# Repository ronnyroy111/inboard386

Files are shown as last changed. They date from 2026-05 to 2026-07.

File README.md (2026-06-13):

# Intel Inboard 386/PC Clone
https://forum.theretroweb.com/t/intel-inboard-386-pc-accelerator-clone/44

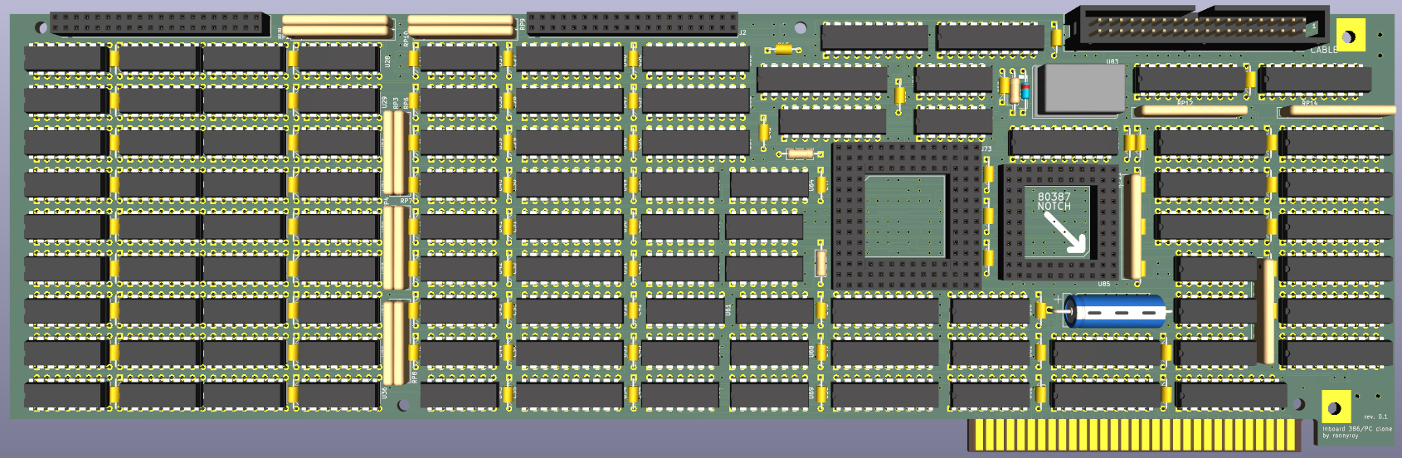
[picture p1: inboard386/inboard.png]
  
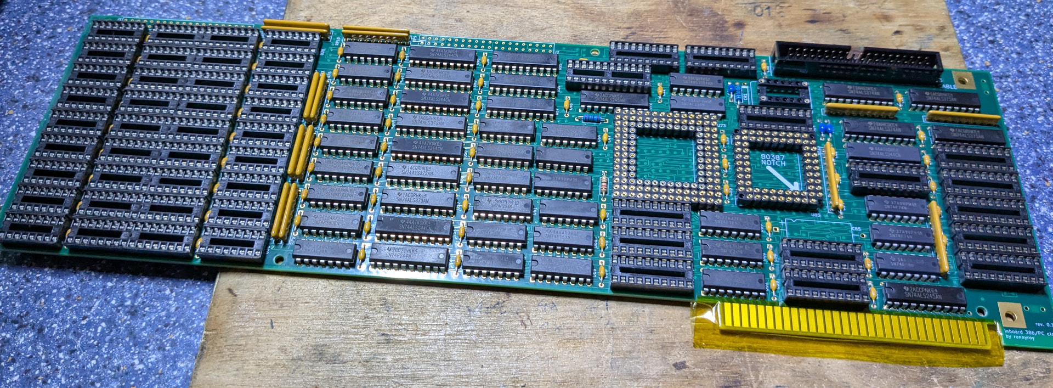
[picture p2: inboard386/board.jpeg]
  
This is a project to reverse engineer and reproduce the [Intel Inboard 386/PC Accelerator Card](https://theretroweb.com/expansioncards/s/intel-inboard-386-pc).  
It's based on a damaged card that i obtained a while ago and managed to fix but decided to sacrifice for a reproduction.  
The Inboard 386/PC is an upgrade card from Intel for the IBM PC/XT and clones that upgraded the 8088 CPU to a 16MHz 386DX and up to 5MB of system memory.  
The card only uses standard 74 series logic chips along with some PALs/PROMs that were luckily not secured and were successfully dumped.  
The PCB is a 6 layer design with 4 signal layers. To aid with reverse engineering it i ended up choosing the destructive route and sanded the entire PCB down to the inner layers.  
By now the PCB design has been completed while the schematic still needs cleanup and further reverse engineering of the programmable logic to completely understand.  

The first revision of the board has been tested and confirmed to be working.  
GAL replacements for the PAL chips and a PROM replacement board have been tested as well.  
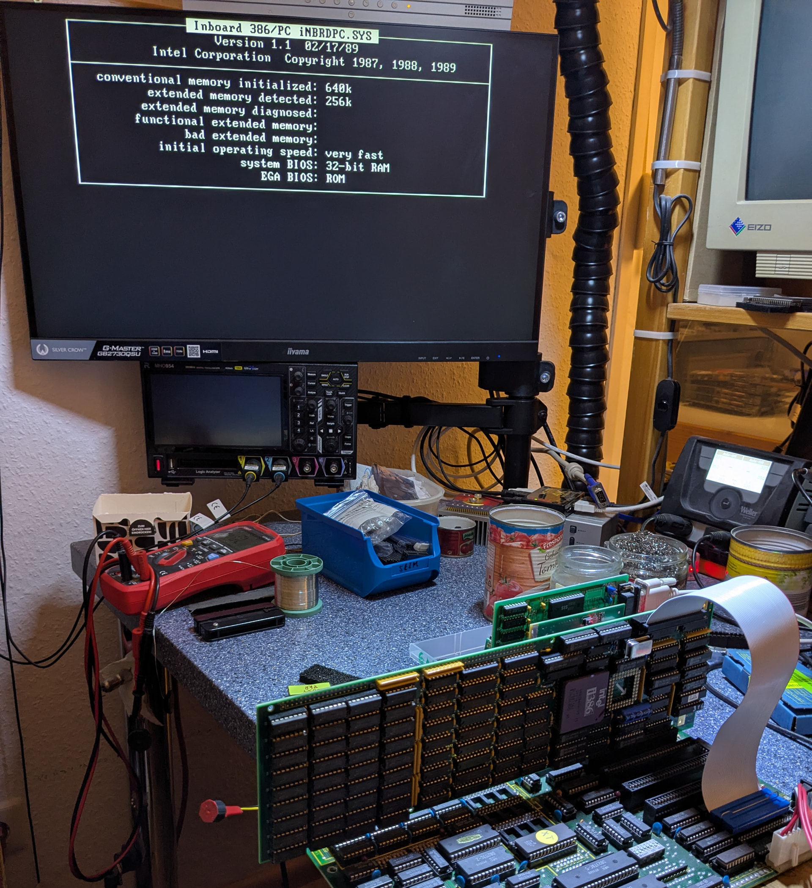
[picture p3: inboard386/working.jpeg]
  
A memory expansion board is currently in work.

This current board design is a 1:1 copy of the original PCB, excluding some small details.  
A future plan is to do a redesign to condense parts of the logic into one or more CPLDs and integrate the optional external memory expansion boards into the design

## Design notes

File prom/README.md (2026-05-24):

A small adapter PCB to replace the 63S281 PROM at U98 with a modern PLCC EEPROM.

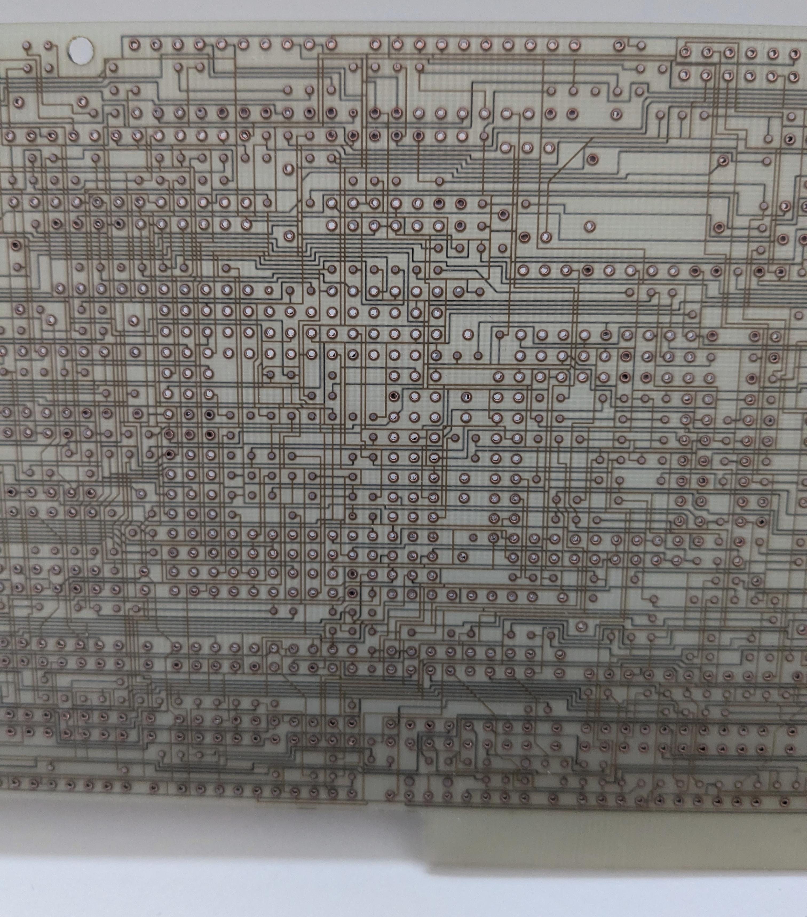
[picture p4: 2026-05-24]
inboard386/inner.jpg

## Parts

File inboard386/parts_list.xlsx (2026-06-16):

Part: | Quantity: | Mouser PN: | MFG PN: | alt Mouser PN: | Notes:
100nF capacitor | 69 | 80-C410C104Z5U | C410C104Z5U5TA | 80-C410C104Z5U-TR
180pF capacitor | 2 | 594-A181K15X7RF5TAA | A181K15X7RF5TAA
22pF capacitor | 1 | 594-A220J15C0GF5UAA | A220J15C0GF5UAA
560µF capacitor | 1 | 594-MAL212636561E3 | MAL212636561E3
115 ohm resistor | 1 | 603-MFR-25FBF52-115R | MFR-25FBF52-115R | 603-MFR-25FRF52-115R
12 ohm resistor | 1 | 603-CFR-25JB-52-12R | CFR-25JB-52-12R
1k ohm resistor | 1 | 603-CFR25SJT-52-1K | CFR25SJT-52-1K
74F74 | 7 | 595-SN74F74N | SN74F74N
74ALS373 | 6 | 595-SN74ALS373AN | SN74ALS373AN
74ALS244 | 5 | 595-SN74ALS244CN | SN74ALS244CN
74ALS245 | 5 | 595-SN74ALS245AN | SN74ALS245AN
74F280 | 4 | 595-SN74F280BN | SN74F280BN
74F258 | 4 | 595-SN74F258N | SN74F258N
74AS1004 | 3 | 595-SN74AS1004AN | SN74AS1004AN |  | could maybe be replaced by a part with regular output strength
74AS1032 | 2 | 595-SN74AS1032AN | SN74AS1032AN |  | could maybe be replaced by a part with regular output strength
74ALS374 | 2 | 595-SN74ALS374AN | SN74ALS374AN
74F244 | 1 | 595-SN74F244N | SN74F244N
74F32 | 1 | 595-SN74F32N | SN74F32N
74AS21 | 1 | 595-SN74AS21N | SN74AS21N
74F00 | 1 | 595-SN74F00N | SN74F00N
74AS1000 | 1 | 595-SN74AS1000AN | SN74AS1000AN |  | could maybe be replaced by a part with regular output strength
74F153 | 1 | 595-SN74F153N | SN74F153N
74LS174 | 1 | 595-SN74LS174N | SN74LS174N
74LS30 | 1 | 595-SN74LS30N | SN74LS30N
74F161 | 1 | 595-SN74F161AN | SN74F161AN
32MHz | 1 | 774-MXO45-3C-32.0 | MXO45-3C-32M0000
74F08 | 1 | 595-SN74F08N | SN74F08N
22 ohm r-network isolated | 6 | 652-4608X-2LF-22 | 4608X-102-220LF
2.2k ohm r-network bussed | 4 | 652-4610X-1LF-2.2K | 4610X-101-222LF
3.3k ohm r-network bussed | 2 | 652-4610X-1LF-3.3K | 4610X-101-332LF
100 ohm r-network bussed | 1 | 652-4610X-1LF-100 | 4610X-101-101LF
10k ohm r-network bussed | 1 | 652-4610X-1LF-10K | 4610X-101-103LF
CPU_Cable | 1 | 737-BHR-40-VUA | BHR-40-VUA | 649-75869-107LF
ATF16V8 | 13 | 556-AF16V8B15PU | ATF16V8B-15PU | 556-AF16V8C7PU | Lattice Gal Chips can be used as well
ATF22V10 | 1 | 556-AF22V10C15PU | ATF22V10C-15PU | 556-AF22V10C7PX | Lattice Gal Chips can be used as well
--------------------- Socket Cable ---------------------
8088 socket connector | 1 | 629-CWR-130-40-0000 | CWR-130-40-0000
IDC connector | 1 | 737-FCS-40-SG | FCS-40-SG
cable | 1 | 517-3365/40FT | 3365/40-CUT-LENGTH
--------------------- PROM adapter ---------------------
EEPROM | 1 | 556-AT28HC64B90JU | AT28HC64B-90JU |  | 27C512 pin compatible and 120ns or faster
PLCC32 socket | 1 | 737-PLCC-32-AT-SMT | PLCC-32-AT-SMT
74F32 | 1 | 595-SN74F32DRE4 | SN74F32DRE4
100nF capacitor | 1 | 581-KAM21BR71H104JT | KAM21BR71H104JT
PinHeader 1x10 | 2
--------------------- source elsewhere ---------------------
41256 dram | 36 |  |  |  | Original are 120ns, faster required for heavy overclocking
PGA-132_14x14 | 1 |  |  |  | can be built from pin strips
80386DX | 1
PGA-68_11x11 | 1 |  |  |  | can be built from pin strips
80387DX | 1
CR1 | 1 | most likely an obsolete 1N34A (or similar) germanium diode |  |  | could maybe be replaced by a shottky diode
Conn_02x20 | 2 | https://aliexpress.com/item/32896689725.html

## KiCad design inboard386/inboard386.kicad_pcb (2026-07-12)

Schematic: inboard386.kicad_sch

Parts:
C1, C2, C3, C4, C5, C6, C7, C8, C9, C10, C11, C12, C13, C14, C15, C16, C17, C18, C19, C20, C21, C22, C23, C24, C25, C26, C27, C28, C29, C30, C31, C32, C33, C34, C35, C36, C37, C38, C39, C40, C41, C42, C43, C44, C45, C46, C47, C48, C49, C50, C51, C53, C54, C55, C56, C57, C58, C59, C62, C63, C64, C66, C67, C68, C69, C70, C71, C72, C73: 100nF; C_Axial_L3.8mm_D2.6mm_P7.62mm_Horizontal_layer
C52: 22pF; C_Axial_L3.8mm_D2.6mm_P7.62mm_Horizontal_layer
C60, C61: 180pF; C_Axial_L3.8mm_D2.6mm_P7.62mm_Horizontal_layer
C65: 560µF; CP_Axial_L21.0mm_D8.0mm_P28.00mm_Horizontal_layer
CR1: 390 mV; D_DO-35_SOD27_P10.16mm_Horizontal_layer
H1, H2: MountingHole_Pad; MountingHole_3.2mm_M3_DIN965_Pad
J1, J2: Conn_02x20_Odd_Even; PinHeader_2x20_P2.54mm_inboard_mem
J3: CPU_Cable; IDC-Header_2x20_P2.54mm_Vertical_layer
J4: Bus_ISA_8bit; BUS_PC
R1: 115; R_Axial_DIN0207_L6.3mm_D2.5mm_P10.16mm_Horizontal_layer
R2: 12; R_Axial_DIN0207_L6.3mm_D2.5mm_P10.16mm_Horizontal_layer
R3: 1k; R_Axial_DIN0207_L6.3mm_D2.5mm_P10.16mm_Horizontal_layer
RP1, RP2, RP9, RP10: 2.2k; R_Array_SIP10_layer
RP3, RP4, RP5, RP6, RP7, RP8: 22; R_Array_SIP8_layer
RP11: 100; R_Array_SIP10_layer
RP12: 10k; R_Array_SIP10_layer
RP13, RP14: 3.3k; R_Array_SIP10_layer
U1, U2, U3, U4, U5, U6, U7, U8, U9, U10, U11, U12, U13, U14, U15, U16, U17, U18, U19, U20, U21, U22, U23, U24, U25, U26, U27, U28, U29, U30, U31, U32, U33, U34, U35, U36: TMM41256AP; DIP-16_W7.62mm_layer
U37, U38, U40, U44: 74F280; DIP-14_W7.62mm_layer
U39, U41, U78: 74AS1004; DIP-14_W7.62mm_layer
U42, U43: 74AS1032; DIP-14_W7.62mm_layer
U45, U62, U63, U66, U67, U92, U93: 74F74; DIP-14_W7.62mm_layer
U46, U48, U50, U53, U90: 74ALS244; DIP-20_W7.62mm_layer
U47, U49, U51, U52, U96, U97: 74ALS373; DIP-20_W7.62mm_layer
U54: 74F244; DIP-20_W7.62mm_layer
U55, U56, U57, U72, U95: 74ALS245; DIP-20_W7.62mm_layer
U58: 74F32; DIP-14_W7.62mm_layer
U59: 74AS21; DIP-14_W7.62mm_layer
U60: 74F00; DIP-14_W7.62mm_layer
U61, U64, U81, U82: 74F258; DIP-16_W7.62mm_layer
U65: 74AS1000; DIP-14_W7.62mm_layer
U68: 74F153; DIP-16_W7.62mm_layer
U69: 74LS174; DIP-16_W7.62mm_layer
U70: PAL16R8; DIP-20_W7.62mm_layer
U71: PAL20L8; DIP-24_W7.62mm_layer
U73: 80386; PGA-132_14x14_37.0x37.0mm
U74: PAL16R4; DIP-20_W7.62mm_layer
U75, U76: PAL16R6; DIP-20_W7.62mm_layer
U77, U84, U87, U91, U100: PAL16L8; DIP-20_W7.62mm_layer
U79: 74LS30; DIP-14_W7.62mm_layer
U80: 74F161; DIP-16_W7.62mm_layer
U83: 32MHz; Oscillator_DIP-14_layer
U85: 80387; PGA-68_11x11_29.2x29.2mm
U86, U101: TIBPAL16R4; DIP-20_W7.62mm_layer
U88, U89: 74ALS374; DIP-20_W7.62mm_layer
U94: 74F08; DIP-14_W7.62mm_layer
U98: 63S281; DIP-20_W7.62mm_layer
U99: TIBPAL16L8; DIP-20_W7.62mm_layer
U102: TIBPAL16R6; DIP-20_W7.62mm_layer

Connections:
387_ERR: U63.8 (~Q), U94.4
8088D_Cp: U86.1 (CLK), U89.11 (Cp), U100.16 (I/~O_{5})
8088D_OE: U89.1 (OE), U100.15 (I/~O_{4})
8088_A8: J3.16 (A8), U96.2 (O0)
8088_A9: J3.14 (A9), U96.5 (O1)
8088_A10: J3.12 (A10), U96.6 (O2)
8088_A11: J3.10 (A11), U96.9 (O3)
8088_A12: J3.8 (A12), U96.12 (O4)
8088_A13: J3.6 (A13), U96.15 (O5)
8088_A14: J3.4 (A14), U96.16 (O6)
8088_A15: J3.3 (A15), U96.19 (O7)
8088_A16/S3: J3.5 (A16/S3), U97.2 (O0)
8088_A17/S4: J3.7 (A17/S4), U97.5 (O1)
8088_A18/S5: J3.9 (A18/S5), U97.6 (O2)
8088_A19/S6: J3.11 (A19/S6), U97.9 (O3)
8088_AD0: J3.32 (AD0), U88.3 (D0), U89.2 (O0), U90.3 (O3b)
8088_AD1: J3.30 (AD1), U89.5 (O1), U90.5 (O2b), U94.1
8088_AD2: J3.28 (AD2), U88.7 (D2), U89.6 (O2), U90.18 (O0a)
8088_AD3: J3.26 (AD3), U88.8 (D3), U89.9 (O3), U90.16 (O1a)
8088_AD4: J3.24 (AD4), U88.13 (D4), U89.12 (O4), U90.14 (O2a)
8088_AD5: J3.22 (AD5), U88.14 (D5), U89.15 (O5), U90.12 (O3a)
8088_AD6: J3.20 (AD6), U88.17 (D6), U89.16 (O6), U90.9 (O0b)
8088_AD7: J3.18 (AD7), U88.18 (D7), U89.19 (O7), U90.7 (O1b)
8088_ALE: U70.17 (~O_{6}), U96.11 (LE), U97.11 (LE), U100.5 (I_{4})
+5V: C1.1, C2.1, C3.1, C4.1, C5.1, C6.1, C7.1, C8.1, C9.1, C10.1, C11.1, C12.1, C13.1, C14.1, C15.1, C16.1, C17.1, C18.1, C19.1, C20.1, C21.1, C22.1, C23.1, C24.1, C25.1, C26.1, C27.1, C28.1, C29.1, C30.1, C31.1, C32.1, C33.1, C34.1, C35.1, C36.1, C37.1, C38.1, C39.1, C40.1, C41.1, C42.1, C43.1, C44.1, C45.1, C46.1, C47.1, C48.1, C49.1, C50.1, C51.1, C53.1, C54.1, C55.1, C56.1, C57.1, C58.1, C59.1, C62.1, C63.1, C64.1, C65.1, C66.1, C67.1, C68.1, C69.1, C70.1, C71.1, C72.1, C73.1, CR1.1 (K), J1.5, J1.17, J1.29, J1.39, J2.9, J2.13, J2.17, J2.21, J2.29, J3.1 (VCC), J4.3 (VCC), J4.29 (VCC), R1.1, RP1.1 (common), RP2.1 (common), RP9.1 (common), RP10.1 (common), RP12.1 (common), RP13.1 (common), RP14.1 (common), U1.8 (V_{CC}), U2.8 (V_{CC}), U3.8 (V_{CC}), U4.8 (V_{CC}), U5.8 (V_{CC}), U6.8 (V_{CC}), U7.8 (V_{CC}), U8.8 (V_{CC}), U9.8 (V_{CC}), U10.8 (V_{CC}), U11.8 (V_{CC}), U12.8 (V_{CC}), U13.8 (V_{CC}), U14.8 (V_{CC}), U15.8 (V_{CC}), U16.8 (V_{CC}), U17.8 (V_{CC}), U18.8 (V_{CC}), U19.8 (V_{CC}), U20.8 (V_{CC}), U21.8 (V_{CC}), U22.8 (V_{CC}), U23.8 (V_{CC}), U24.8 (V_{CC}), U25.8 (V_{CC}), U26.8 (V_{CC}), U27.8 (V_{CC}), U28.8 (V_{CC}), U29.8 (V_{CC}), U30.8 (V_{CC}), U31.8 (V_{CC}), U32.8 (V_{CC}), U33.8 (V_{CC}), U34.8 (V_{CC}), U35.8 (V_{CC}), U36.8 (V_{CC}), U37.14 (VCC), U38.14 (VCC), U39.14 (VCC), U40.14 (VCC), U41.14 (VCC), U42.14 (VCC), U43.14 (VCC), U44.14 (VCC), U45.14 (VCC), U46.20 (VCC), U47.20 (VCC), U48.20 (VCC), U49.20 (VCC), U50.20 (VCC), U51.20 (VCC), U52.20 (VCC), U53.20 (VCC), U54.4 (I1a), U54.20 (VCC), U55.20 (VCC), U56.20 (VCC), U57.20 (VCC), U58.14 (VCC), U59.14 (VCC), U60.14 (VCC), U61.16 (VCC), U62.4 (~S), U62.13 (~R), U62.14 (VCC), U63.1 (~R), U63.13 (~R), U63.14 (VCC), U64.16 (VCC), U65.14 (VCC), U66.1 (~R), U66.4 (~S), U66.13 (~R), U66.14 (VCC), U67.10 (~S), U67.13 (~R), U67.14 (VCC), U68.16 (VCC), U69.14 (D5), U69.16 (VCC), U70.20 (V_{CC}), U71.24 (V_{CC}), U72.20 (VCC), U73.A1 (VCC), U73.A5 (VCC), U73.A7 (VCC), U73.A10 (VCC), U73.A14 (VCC), U73.C5 (VCC), U73.C12 (VCC), U73.D12 (VCC), U73.G2 (VCC), U73.G3 (VCC), U73.G12 (VCC), U73.G14 (VCC), U73.L12 (VCC), U73.M3 (VCC), U73.M7 (VCC), U73.M13 (VCC), U73.N4 (VCC), U73.N7 (VCC), U73.P2 (VCC), U73.P8 (VCC), U74.20 (V_{CC}), U75.20 (V_{CC}), U76.20 (V_{CC}), U77.20 (V_{CC}), U78.14 (VCC), U79.14 (VCC), U80.10 (CET), U80.16 (VCC), U81.16 (VCC), U82.16 (VCC), U83.14 (Vcc), U84.20 (V_{CC}), U85.A6 (VCC), U85.A9 (VCC), U85.B4 (VCC), U85.E1 (VCC), U85.F1 (VCC), U85.F10 (VCC), U85.J2 (VCC), U85.J11 (CKM), U85.K3 (TIE_HIGH), U85.K5 (VCC), U85.L4 (STEN), U85.L7 (VCC), U85.L9 (TIE_HIGH), U86.20 (V_{CC}), U87.20 (V_{CC}), U88.20 (VCC), U89.20 (VCC), U90.20 (VCC), U91.20 (V_{CC}), U92.4 (~S), U92.10 (~S), U92.13 (~R), U92.14 (VCC), U93.1 (~R), U93.10 (~S), U93.13 (~R), U93.14 (VCC), U94.14 (VCC), U95.20 (VCC), U96.20 (VCC), U97.20 (VCC), U98.20 (VCC), U99.20 (V_{CC}), U100.20 (V_{CC}), U101.20 (V_{CC}), U102.20 (V_{CC})
A0: U70.15 (~O_{4}), U77.6 (I_{5}), U86.7 (I_{6}), U90.17 (I3b), U98.1 (A0), U99.2 (I_{1}), U100.7 (I_{6})
A1: U70.16 (~O_{5}), U77.5 (I_{4}), U86.6 (I_{5}), U90.15 (I2b), U98.2 (A1), U99.1 (I_{0}), U100.6 (I_{5})
A2: U64.13 (I1c), U73.C4 (A2), U74.5 (I_{4}), U85.L8 (CMD0#), U90.2 (I0a), U98.3 (A2), U100.8 (I_{7})
A3: U64.10 (I1d), U73.A3, U90.4 (I1a), U98.4 (A3)
A4: U64.6 (I1b), U73.B3 (A4), U90.6 (I2a), U98.5 (A4)
A5: U64.3 (I1a), U73.B2 (A5), U84.11 (I_{9}), U86.3 (I_{2}), U90.8 (I3a), U98.17 (A5)
A6: U61.13 (I1c), U73.C3 (A6), U84.9 (I_{8}), U90.11 (I0b), U98.18 (A6), U100.9 (I_{8}), U101.2 (I_{1})
A7: U61.10 (I1d), U73.C2 (A7), U84.8 (I_{7}), U90.13 (I1b), U98.19 (A7)
A8: U61.6 (I1b), U73.C1 (A8), U84.7 (I_{6}), U96.3 (D0)
A9: U64.14 (I0c), U73.D3 (A9), U84.6 (I_{5}), U96.4 (D1), U101.3 (I_{2})
A10: U64.11 (I0d), U73.D2 (A10), U84.5 (I_{4}), U96.7 (D2)
A11: U64.5 (I0b), U73.D1 (A11), U96.8 (D3)
A12: U64.2 (I0a), U73.E3 (A12), U96.13 (D4)
A13: U61.14 (I0c), U73.E2 (A13), U96.14 (D5)
A14: U61.11 (I0d), U73.E1 (A14), U96.17 (D6)
A15: U68.13 (I3b), U73.F1 (A15), U96.18 (D7)
A16: U68.3 (I3a), U71.7 (I_{6}), U73.G1 (A16), U97.3 (D0)
A17: U68.12 (I2b), U71.6 (I_{5}), U73.H1 (A17), U97.4 (D1)
A18: U71.5 (I_{4}), U73.H2 (A18), U97.7 (D2)
A19: U71.4 (I_{3}), U73.H3 (A19), U97.8 (D3)
A20: U61.2 (I0a), U71.3 (I_{2}), U73.J1 (A20)
A21: U61.3 (I1a), U71.2 (I_{1}), U73.K1 (A21)
A22: U71.1 (I_{0}), U73.K2 (A22)
A23: U71.8 (I_{7}), U73.L1 (A23)
A30: U73.P1 (A30), U97.17 (D6)
A30L: U58.5, U78.11, U97.16 (O6)
A31: U73.N2 (A31), U84.4 (I_{3}), U85.K6 (NPS2)
A->AD: U90.1 (OEa), U90.19 (OEb), U100.12 (~O_{1})
AEN: J4.42 (AEN), U58.1, U62.2 (D), U87.9 (I_{8}), U102.2 (I_{1})
AEN_BUF: U62.5 (Q), U75.5 (I_{4})
BA00: J4.62 (BA00), U91.8 (I_{7}), U99.4 (I_{3})
BA01: J4.61 (BA01), U91.9 (I_{8}), U99.3 (I_{2})
BA02: J4.60 (BA02), U82.13 (I1c)
BA03: J4.59 (BA03), U82.10 (I1d)
BA04: J4.58 (BA04), U82.6 (I1b)
BA05: J4.57 (BA05), U82.3 (I1a)
BA06: J4.56 (BA06), U81.13 (I1c)
BA07: J4.55 (BA07), U81.10 (I1d)
BA08: J4.54 (BA08), U81.6 (I1b)
BA09: J4.53 (BA09), U82.14 (I0c)
BA10: J4.52 (BA10), U82.11 (I0d)
BA11: J4.51 (BA11), U82.5 (I0b)
BA12: J4.50 (BA12), U82.2 (I0a)
BA13: J4.49 (BA13), U81.14 (I0c)
BA14: J4.48 (BA14), U81.11 (I0d)
BA15: J4.47 (BA15), U91.13 (I/~O_{2})
BA16: J4.46 (BA16), U91.18 (I/~O_{7})
BA17: J4.45 (BA17), U68.10 (I0b), U87.3 (I_{2})
BA18: J4.44 (BA18), U87.2 (I_{1})
BA19: J4.43 (BA19), U81.5 (I0b), U87.1 (I_{0})
BUSDIR: U55.1 (A->B), U56.1 (A->B), U57.1 (A->B), U72.1 (A->B), U95.1 (A->B), U99.15 (I/~O_{4})
CLK: U45.3 (C), U62.3 (C), U62.11 (C), U63.3 (C), U66.11 (C), U67.5 (Q), U74.6 (I_{5}), U75.9 (I_{8}), U76.9 (I_{8}), U80.2 (CP)
CLK2: R2.2, U66.3 (C), U67.3 (C), U67.11 (C), U73.F12 (CLK2), U74.1 (CLK), U75.1 (CLK), U76.1 (CLK), U85.K10 (CPUCLK2)
CLK88: C52.1, CR1.2 (A), J3.38 (CLK), R3.1, U78.1
CLK88_BUF: U78.4, U92.3 (C), U93.3 (C), U93.11 (C)
D0: U52.2 (O0), U53.17 (I3b), U69.3 (D0), U73.H12 (D0), U85.H2 (D0)
D1: U52.5 (O1), U53.15 (I2b), U69.4 (D1), U73.H13 (D1), U85.H1 (D1)
D2: U52.6 (O2), U53.13 (I1b), U69.6 (D2), U73.H14 (D2), U85.G2 (D2)
D3: U52.9 (O3), U53.11 (I0b), U69.11 (D3), U73.J14 (D3), U85.G1 (D3)
D4: U52.12 (O4), U53.8 (I3a), U69.13 (D4), U73.K14 (D4), U85.D2 (D4)
D5: U52.15 (O5), U53.6 (I2a), U73.K13 (D5), U85.D1 (D5)
D6: U52.16 (O6), U53.4 (I1a), U73.L14 (D6), U85.C2 (D6)
D7: U52.19 (O7), U53.2 (I0a), U73.K12 (D7), U85.C1 (D7)
D8: U50.17 (I3b), U51.2 (O0), U73.L13 (D8), U85.B1 (D8)
D9: U50.15 (I2b), U51.5 (O1), U73.N14 (D9), U85.A2 (D9)
D10: U50.13 (I1b), U51.6 (O2), U73.M12 (D10), U85.B3 (D10)
D11: U50.11 (I0b), U51.9 (O3), U73.N13 (D11), U85.A3 (D11)
D12: U50.8 (I3a), U51.12 (O4), U73.N12 (D12), U85.A4 (D12)
D13: U50.6 (I2a), U51.15 (O5), U73.P13 (D13), U85.B5 (D13)
D14: U50.4 (I1a), U51.16 (O6), U73.P12 (D14), U85.A5 (D14)
D15: U50.2 (I0a), U51.19 (O7), U73.M11 (D15), U85.B6 (D15)
D16: U48.17 (I3b), U49.2 (O0), U73.N11 (D16), U85.A7 (D16)
D17: U48.15 (I2b), U49.5 (O1), U73.N10 (D17), U85.B8 (D17)
D18: U48.13 (I1b), U49.6 (O2), U73.P11 (D18), U85.A8 (D18)
D19: U48.11 (I0b), U49.9 (O3), U73.P10 (D19), U85.B9 (D19)
D20: U48.8 (I3a), U49.12 (O4), U73.M9 (D20), U85.B10 (D20)
D21: U48.6 (I2a), U49.15 (O5), U73.N9 (D21), U85.A10 (D21)
D22: U48.4 (I1a), U49.16 (O6), U73.P9 (D22), U85.B11 (D22)
D23: U48.2 (I0a), U49.19 (O7), U73.N8 (D23), U85.C10 (D23)
D24: U46.17 (I3b), U47.2 (O0), U73.P7 (D24), U85.D10 (D24)
D25: U46.15 (I2b), U47.5 (O1), U73.N6 (D25), U85.D11 (D25)
D26: U46.13 (I1b), U47.6 (O2), U73.P5 (D26), U85.E10 (D26)
D27: U46.11 (I0b), U47.9 (O3), U73.N5 (D27), U85.E11 (D27)
D28: U46.8 (I3a), U47.12 (O4), U73.M6 (D28), U85.G10 (D28)
D29: U46.6 (I2a), U47.15 (O5), U73.P4 (D29), U85.G11 (D29)
D30: U46.4 (I1a), U47.16 (O6), U73.P3 (D30), U85.H10 (D30)
D31: U46.2 (I0a), U47.19 (O7), U73.M5 (D31), U85.H11 (D31)
D->MD_OE: U46.1 (OEa), U46.19 (OEb), U48.1 (OEa), U48.19 (OEb), U50.1 (OEa), U50.19 (OEb), U53.1 (OEa), U53.19 (OEb), U60.8
DACK0: U71.11 (I_{10}), U74.18 (I/~O_{7}), U78.8, U87.11 (I_{9}), U91.6 (I_{5})
DB0: J4.40 (DB0), RP13.3 (R2), U95.18 (B0)
DB0B: RP14.9 (R8), U55.18 (B0), U56.18 (B0), U57.18 (B0), U72.18 (B0), U79.1, U88.2 (O0), U89.3 (D0), U95.2 (A0), U98.6 (O1)
DB1: J4.39 (DB1), RP13.4 (R3), U95.17 (B1)
DB1B: RP14.8 (R7), U55.17 (B1), U56.17 (B1), U57.17 (B1), U72.17 (B1), U88.5 (O1), U89.4 (D1), U95.3 (A1), U98.7 (O2), U102.8 (I_{7})
DB2: J4.38 (DB2), RP13.5 (R4), U95.16 (B2)
DB2B: RP14.7 (R6), U55.16 (B2), U56.16 (B2), U57.16 (B2), U72.16 (B2), U79.2, U86.2 (I_{1}), U88.6 (O2), U95.4 (A2), U98.8 (O3)
DB3: J4.37 (DB3), RP13.6 (R5), U95.15 (B3)
DB3B: RP14.6 (R5), U55.15 (B3), U56.15 (B3), U57.15 (B3), U72.15 (B3), U79.3, U86.19 (I/~O_{8}), U88.9 (O3), U89.8 (D3), U95.5 (A3), U98.9 (O4)
DB4: J4.36 (DB4), RP13.7 (R6), U95.14 (B4)
DB4B: RP14.5 (R4), U55.14 (B4), U56.14 (B4), U57.14 (B4), U72.14 (B4), U79.4, U88.12 (O4), U89.13 (D4), U95.6 (A4), U98.11 (O5)
DB5: J4.35 (DB5), RP13.8 (R7), U95.13 (B5)
DB5B: RP14.4 (R3), U55.13 (B5), U56.13 (B5), U57.13 (B5), U72.13 (B5), U88.15 (O5), U89.14 (D5), U95.7 (A5), U98.12 (O6), U102.7 (I_{6})
DB6: J4.34 (DB6), RP13.9 (R8), U95.12 (B6)
DB6B: RP14.3 (R2), U55.12 (B6), U56.12 (B6), U57.12 (B6), U72.12 (B6), U79.5, U88.16 (O6), U89.17 (D6), U95.8 (A6), U98.13 (O7)
DB7: J4.33 (DB7), RP13.10 (R9), U95.11 (B7)
DB7B: RP14.2 (R1), U55.11 (B7), U56.11 (B7), U57.11 (B7), U72.11 (B7), U79.6, U86.18 (I/~O_{7}), U88.19 (O7), U89.18 (D7), U95.9 (A7), U98.14 (O8)
DB_EN: U87.12 (~O_{1}), U95.19 (CE)
D/~C: U73.A11 (D/~C), U77.9 (I_{8}), U84.2 (I_{1})
ERROR387: U63.11 (C), U78.6
FPU_STAT_SET: U42.13, U63.10 (~S), U74.16 (~O_{5})
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

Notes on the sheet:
U75 Outputs: 13-18
!!! pinout of the diode is marked weird on the board
U76 Outputs: 13-19
U102 Outputs: 13-19
U99 Outputs: 12 14-19
!!!!!!
U91 Outputs: 12 14-17 19
U101 Outputs: 13-17 19
U70 Outputs: 12-19
U71 Outputs: 15 17-22
????
U100 Outputs: 12-13 15-19
U87 Outputs: 12 15-19 16 cond. OE
U74 Outputs: 12-17
U77 Outputs: 12-15 17-19
U86 Outputs: 12-17
U84 Outputs: 12 15-19

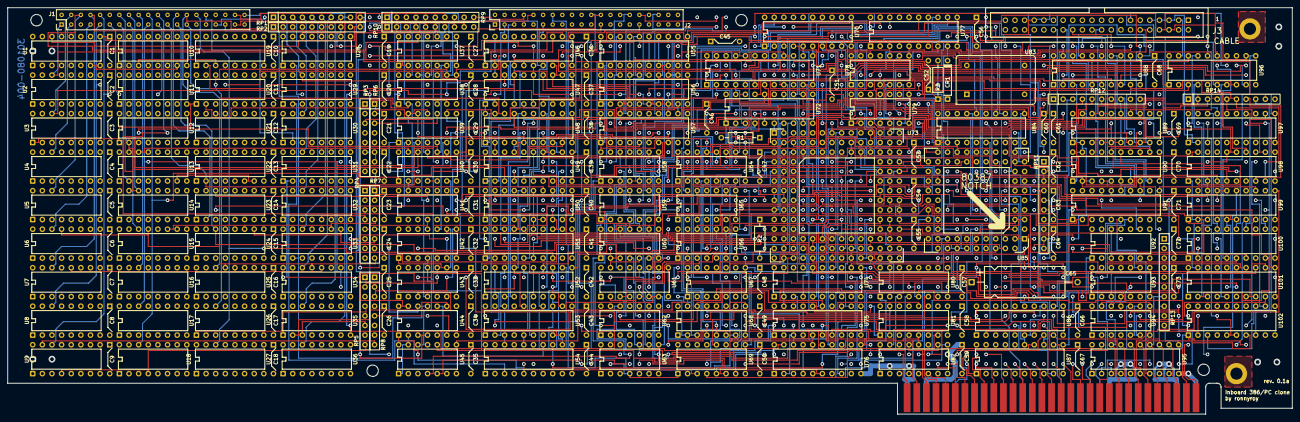
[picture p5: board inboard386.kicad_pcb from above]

Board: 6 copper layers, 338.8 x 107.2 mm, 199 parts (0 on the bottom side), 382 nets.

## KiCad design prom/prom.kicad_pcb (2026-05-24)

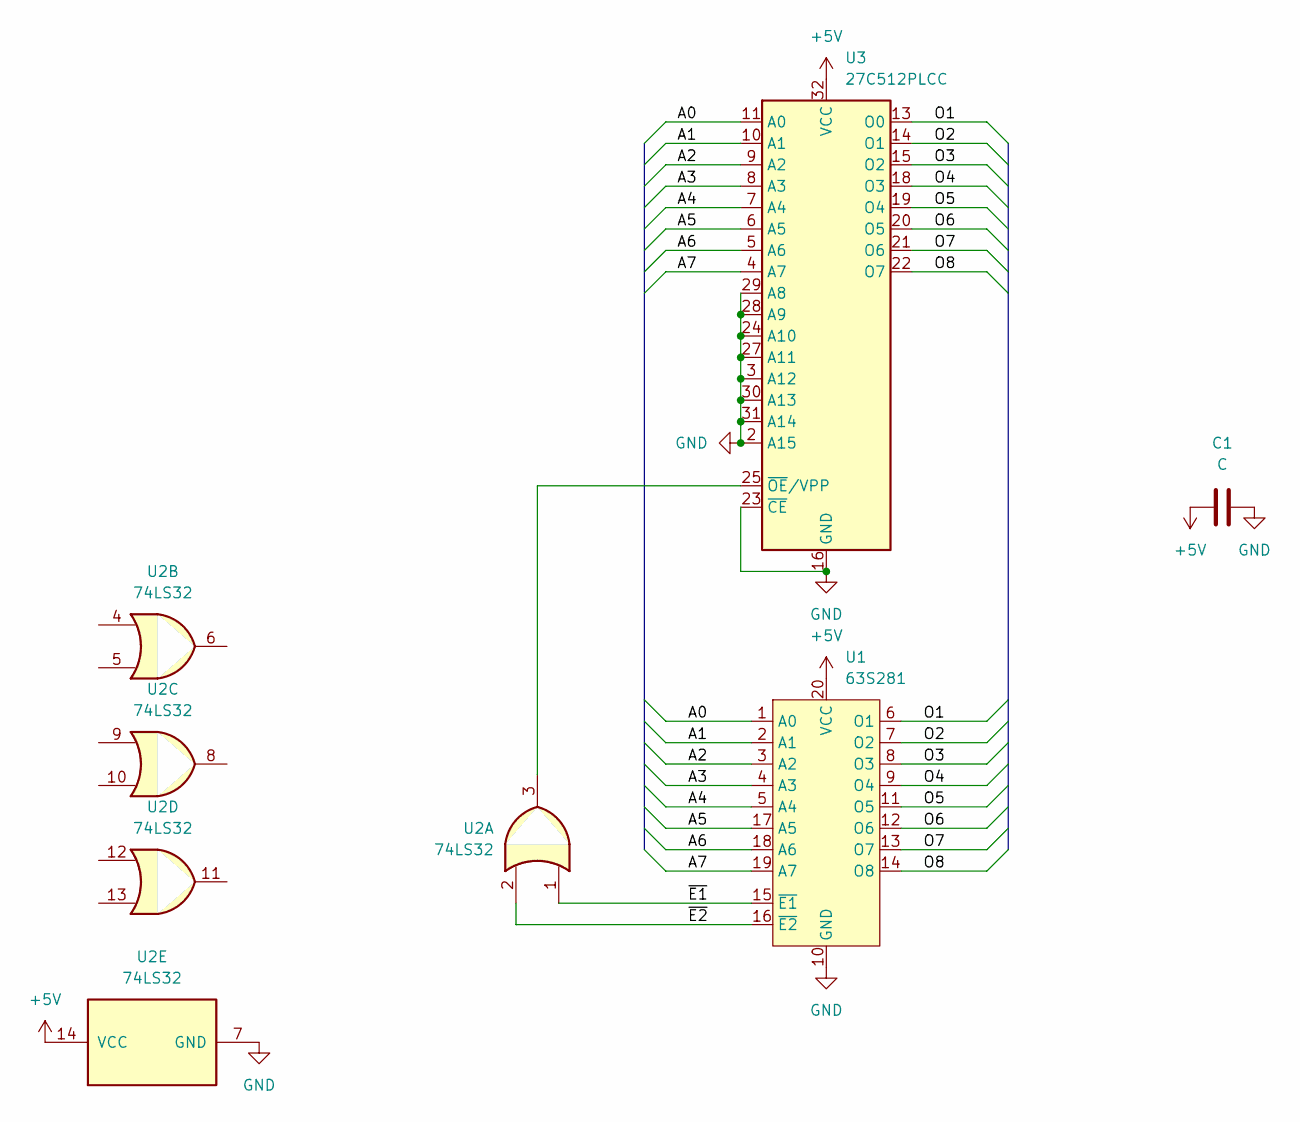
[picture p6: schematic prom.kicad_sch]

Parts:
C1: C; C_0805_2012Metric_Pad1.18x1.45mm_HandSolder
U1: 63S281; DIP-20_W7.62mm
U2: 74LS32; SOIC-14_3.9x8.7mm_P1.27mm
U3: 27C512PLCC; PLCC-32_11.4x14.0mm_P1.27mm

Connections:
+5V: C1.1, U1.20 (VCC), U2.14 (VCC), U3.32 (VCC)
/A0: U1.1 (A0), U3.11 (A0)
/A1: U1.2 (A1), U3.10 (A1)
/A2: U1.3 (A2), U3.9 (A2)
/A3: U1.4 (A3), U3.8 (A3)
/A4: U1.5 (A4), U3.7 (A4)
/A5: U1.17 (A5), U3.6 (A5)
/A6: U1.18 (A6), U3.5 (A6)
/A7: U1.19 (A7), U3.4 (A7)
/O1: U1.6 (O1), U3.13 (O0)
/O2: U1.7 (O2), U3.14 (O1)
/O3: U1.8 (O3), U3.15 (O2)
/O4: U1.9 (O4), U3.18 (O3)
/O5: U1.11 (O5), U3.19 (O4)
/O6: U1.12 (O6), U3.20 (O5)
/O7: U1.13 (O7), U3.21 (O6)
/O8: U1.14 (O8), U3.22 (O7)
/~E1: U1.15 (~E1), U2.1
/~E2: U1.16 (~E2), U2.2
GND: C1.2, U1.10 (GND), U2.7 (GND), U3.2 (A15), U3.3 (A12), U3.16 (GND), U3.23 (~CE), U3.24 (A10), U3.27 (A11), U3.28 (A9), U3.29 (A8), U3.30 (A13), U3.31 (A14)
unnamed: U2.3, U3.25 (~OE/VPP)

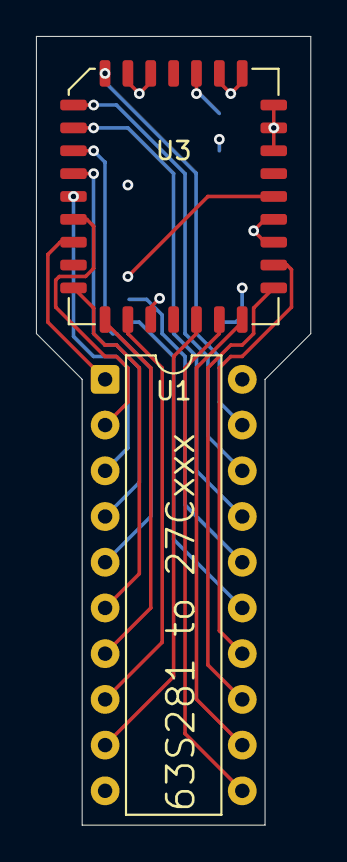
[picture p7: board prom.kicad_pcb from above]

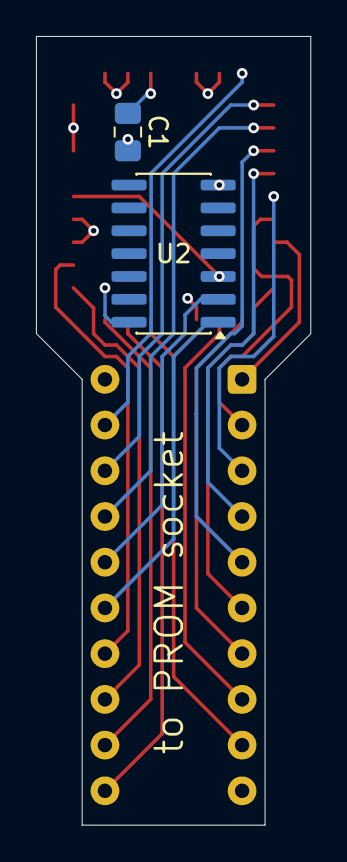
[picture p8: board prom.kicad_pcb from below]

Board: 4 copper layers, 15.2 x 43.8 mm, 4 parts (2 on the bottom side), 21 nets.

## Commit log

2026-05-24 Initial project commit. PCB design rev. 0.1
    [inboard386.kicad_pcb, inboard386.kicad_sch, prom.kicad_pcb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]
2026-06-13 minimal updates to schematic labelling
    [inboard386.kicad_sch]
2026-06-13 Add pictures of assmebled and running board
2026-06-13 Update README with board images and project status
2026-06-16 Add parts list spreadsheet
    [parts_list.xlsx]
2026-06-16 Add PROM adapter components to parts list
    [parts_list.xlsx]
2026-07-12 update signal names in schematic and logic, add prototype logic for 8MB ram expansion
    [inboard386.kicad_pcb, inboard386.kicad_sch]
2026-08-26 Update signal names on logic and schematic, update logic of U71 to allow addressing over 8MB of memory.
    [inboard386.kicad_sch]
